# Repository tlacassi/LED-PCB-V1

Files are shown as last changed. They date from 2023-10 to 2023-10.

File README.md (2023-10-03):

# LED-PCB-V1

Une vidéo qui explique le minimum nécessaire pour faire tourner l'ESP sur un pcb : https://www.youtube.com/watch?v=tQ0dL_9M1wI&t=242s

Le projet WLED pour le soft et les intégrations : https://kno.wled.ge

Datasheet WS2815b : https://www.marutsu.co.jp/contents/shop/marutsu/datasheet/WS2815B.pdf

Datasheet ESP32 : https://www.espressif.com/sites/default/files/documentation/esp32-s3-wroom-1_wroom-1u_datasheet_en.pdf

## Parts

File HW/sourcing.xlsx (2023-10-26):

Reference | Qty | Value | Footprint | REF 1 | Prix 1 CHF | REF 2 | Prix 2 CHF | REF 3 | Prix 3 CHF
Régulateur | 1 | 5v to 3v3 | Package_TO_SOT_SMD:TO-252-3_TabPin2 | AZ1117CR-3.3TRG1 | 0.307
DCDC | 1 | 12v to 5v | Package_TO_SOT_SMD:TO-252-3_TabPin2 | TSR-1-2450 | 4.99
Condensateurs : C1, C2, C3, C4, C6, C7, C9, C10, C11, C15 | 10 | 100nF |  | MCASU105SB7104KFNA01 | 0.49
Condensateurs : C5, C8 | 2 | 1000uF/50V |  | A768MS108M1CLAE015 | 1.642 | EMZS250ARA102MJA0G | 1.57
Condensateurs : C12, C13, C14 | 3 | 1uF |  | GRM155C71C105KE11D | 0.27
Microcontrôleur | 1 | ESP32 |  | ESP32-S3-WROOM-1-N8 | 2.89
Fusible F1 | 1 | 7A |  | 5MF 7-R | 0.541 | 0235007.MXP | 0.406 | BK1/GMA-7-R | 0.541
Porte fusible | 1 | Porte fuse 5*20mm |  | 0031.8201.G | 0.767 | BK1/HTC-100M | 0.722
Connecteur USB C : J1 | 1 | USB_C_Receptacle |  | 216990-0002 | 0.837
Connecteurs de sortie : J5, J7 | 2 | 4 pins right angle |  | 39-30-3041 | 1.552
Connecteur d'alimentation | 1 | Jack-DC |  | PJ-057AH | 0.965 | 694106301002 | 0.921
Level shifter | 1 | 0-3.3V to 0-5V |  | SN74AHCT125DR | 0.335
Relais | 1 |  |  | AHQSH112LM1F00G | 0.837
Diode de roue libre | 1 |  |  | 1N4148W_R1_00001 | 0.121
Transistor commande relais | 1 |  |  | MMBT3904-7-F | 0.102
Bouton reset | 1 |  |  | TS14-1212-140-BK-160-SCR-D | 0.251
Nb PCB
10

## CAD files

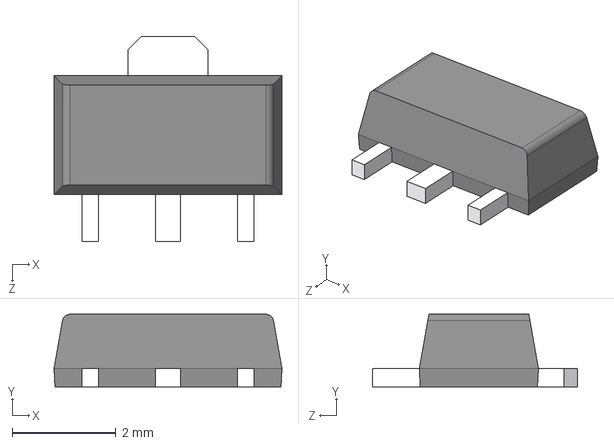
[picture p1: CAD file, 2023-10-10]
HW/wled_V1/AZ1117CR-3.3TRG1.stp
4.40 x 1.40 x 3.95 mm

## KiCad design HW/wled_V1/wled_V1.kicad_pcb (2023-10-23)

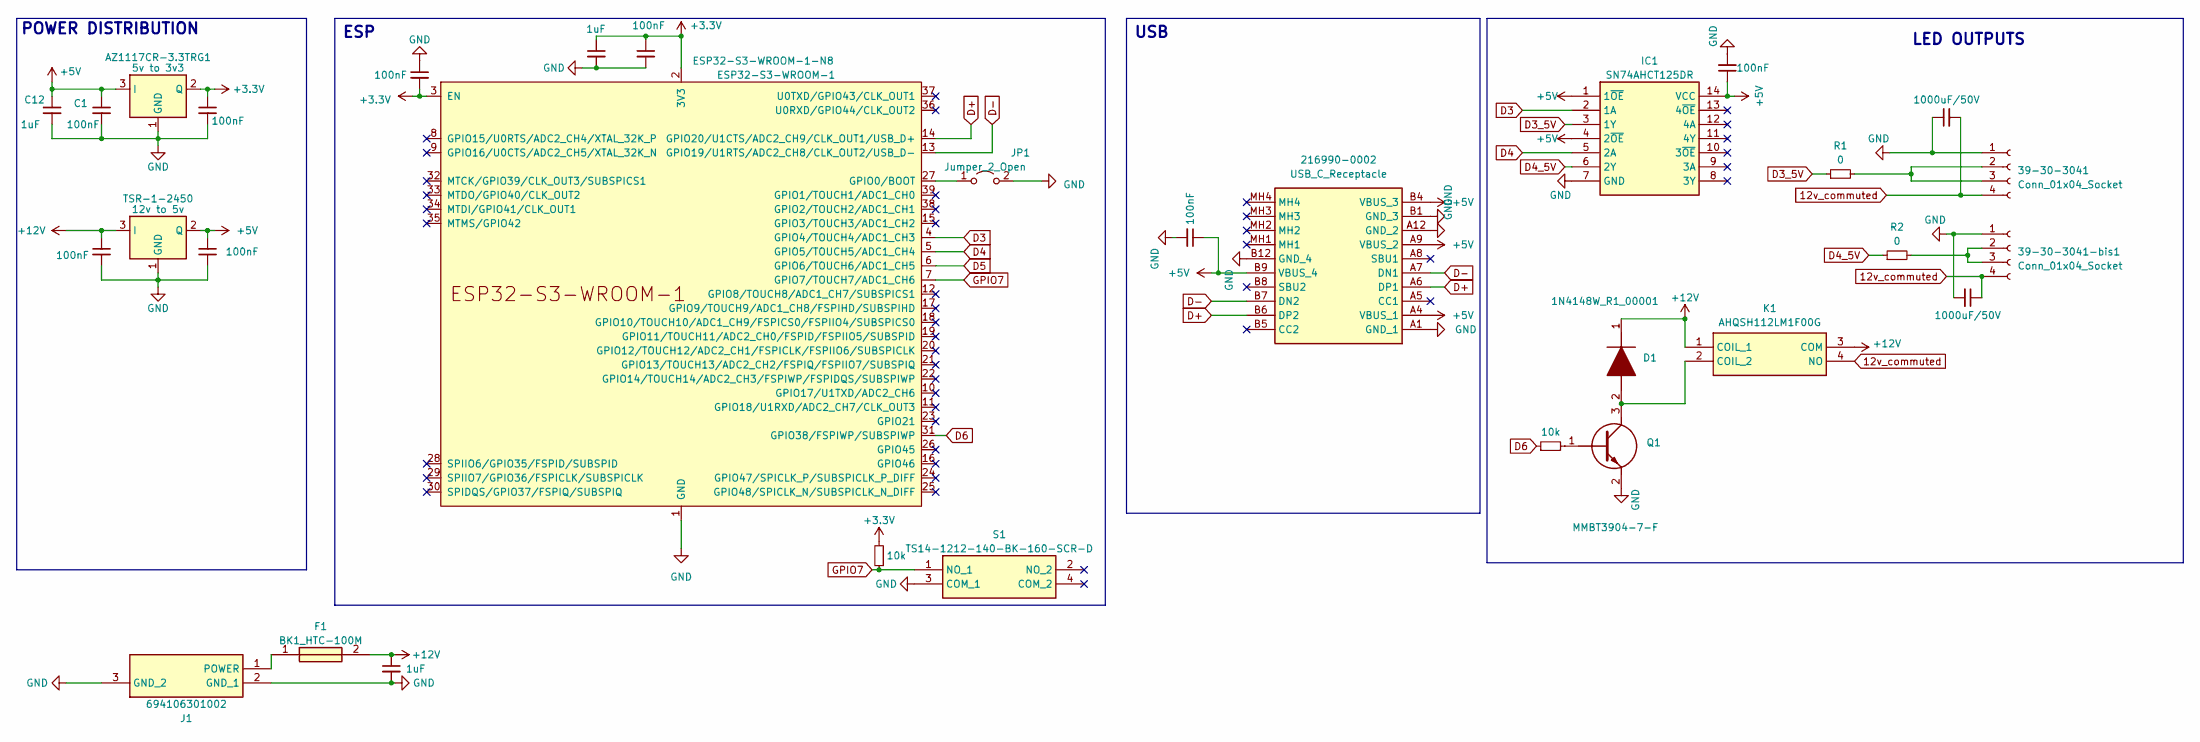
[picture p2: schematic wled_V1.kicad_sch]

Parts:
39-30-3041, 39-30-3041-bis1: Conn_01x04_Socket; 39303041
216990-0002: USB_C_Receptacle; 2169900002; Mouser Part Number 538-216990-0002
AZ1117CR-3.3TRG1: 5v to 3v3; AZ1117CR33TRG1
C1, C2, C3, C4, C6, C9, C11, C0402C103K1RACAUTO1: 100nF; CAPC1005X55N
C5, C8: 1000uF/50V; CAPAE1030X1050N
C12, C13, C14: 1uF; CAPC1005X55N
D1: 1N4148W_R1_00001; SOD3816X135N; Mouser Part Number 241-1N4148W_R1_00001
ESP32-S3-WROOM-1-N8: ESP32-S3-WROOM-1; ESP32S3WROOM1N8R8
F1: BK1_HTC-100M; BK1HTC100M; Mouser Part Number 504-BK1-HTC-100M
IC1: SN74AHCT125DR; SOIC127P600X175-14N; Mouser Part Number 595-SN74AHCT125DR
J1: 694106301002; 694106301002_1; Mouser Part Number 710-694106301002
JP1: Jumper_2_Open; SolderJumper-2_P1.3mm_Bridged2Bar_Pad1.0x1.5mm
K1: AHQSH112LM1F00G; Mouser Part Number 523-AHQSH112LM1F00G
Q1: MMBT3904-7-F; SOT96P240X110-3N; Mouser Part Number 621-MMBT3904-F
R1, R2: 0; R_0603_1608Metric_Pad0.98x0.95mm_HandSolder
RN73H1JTTD1002F1, RN73H1JTTD1002F50: 10k; R_0603_1608Metric_Pad0.98x0.95mm_HandSolder
S1: TS14-1212-140-BK-160-SCR-D; TS0266160BK260LCRD; Manufacturer_Part_Number TS14-1212-140-BK-160-SCR-D
TSR-1-2450: 12v to 5v; TSR12450

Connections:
12v_commuted: 39-30-3041.4, 39-30-3041-bis1.4, C5.1, C8.2, K1.4 (NO)
+3.3V: AZ1117CR-3.3TRG1.2 (Q), C2.1, C6.2, C14.1, C0402C103K1RACAUTO1.1, ESP32-S3-WROOM-1-N8.2 (3V3), ESP32-S3-WROOM-1-N8.3 (EN), RN73H1JTTD1002F1.2; also elsewhere on the board
+5V: 216990-0002.A4 (VBUS_1), 216990-0002.A9 (VBUS_2), 216990-0002.B4 (VBUS_3), 216990-0002.B9 (VBUS_4), AZ1117CR-3.3TRG1.3 (I), C1.1, C4.1, C9.1, C11.1, C12.1, IC1.1 (1~OE), IC1.4 (2~OE), IC1.14 (VCC), TSR-1-2450.2 (Q)
+12V: C3.1, C13.1, D1.1 (K), F1.2, K1.1 (COIL_1), K1.3 (COM), TSR-1-2450.3 (I)
D3: ESP32-S3-WROOM-1-N8.4 (GPIO4/TOUCH4/ADC1_CH3), IC1.2 (1A)
D3_5V: IC1.3 (1Y), R1.1
D4: ESP32-S3-WROOM-1-N8.5 (GPIO5/TOUCH5/ADC1_CH4), IC1.5 (2A)
D4_5V: IC1.6 (2Y), R2.1
D5: ESP32-S3-WROOM-1-N8.6 (GPIO6/TOUCH6/ADC1_CH5)
D6: ESP32-S3-WROOM-1-N8.31 (GPIO38/FSPIWP/SUBSPIWP), RN73H1JTTD1002F50.1
D+: 216990-0002.A6 (DP1), 216990-0002.B6 (DP2), ESP32-S3-WROOM-1-N8.14 (GPIO20/U1CTS/ADC2_CH9/CLK_OUT1/USB_D+)
D-: 216990-0002.A7 (DN1), 216990-0002.B7 (DN2), ESP32-S3-WROOM-1-N8.13 (GPIO19/U1RTS/ADC2_CH8/CLK_OUT2/USB_D-)
GND: 39-30-3041.1, 39-30-3041-bis1.1, 216990-0002.A1 (GND_1), 216990-0002.A12 (GND_2), 216990-0002.B1 (GND_3), 216990-0002.B12 (GND_4), AZ1117CR-3.3TRG1.1 (GND), C1.2, C3.2, C4.2, C5.2, C8.1, C9.2, C11.2, C12.2, C13.2, C14.2, C0402C103K1RACAUTO1.2, ESP32-S3-WROOM-1-N8.1 (GND), ESP32-S3-WROOM-1-N8.40 (GND), ESP32-S3-WROOM-1-N8.41 (GND), IC1.7 (GND), J1.2 (GND_1), J1.3 (GND_2), JP1.2 (B), Q1.2 (E), S1.3 (COM_1), TSR-1-2450.1 (GND); also elsewhere on the board
GPIO7: ESP32-S3-WROOM-1-N8.7 (GPIO7/TOUCH7/ADC1_CH6), RN73H1JTTD1002F1.1, S1.1 (NO_1)
unnamed: 39-30-3041.2, 39-30-3041.3, R1.2
unnamed: 39-30-3041-bis1.2, 39-30-3041-bis1.3, R2.2
unnamed: D1.2 (A), K1.2 (COIL_2), Q1.3 (C)
unnamed: ESP32-S3-WROOM-1-N8.27 (GPIO0/BOOT), JP1.1 (A)
unnamed: F1.1, J1.1 (POWER)
unnamed: Q1.1 (B), RN73H1JTTD1002F50.2

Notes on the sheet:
USB
LED OUTPUTS
ESP
POWER DISTRIBUTION

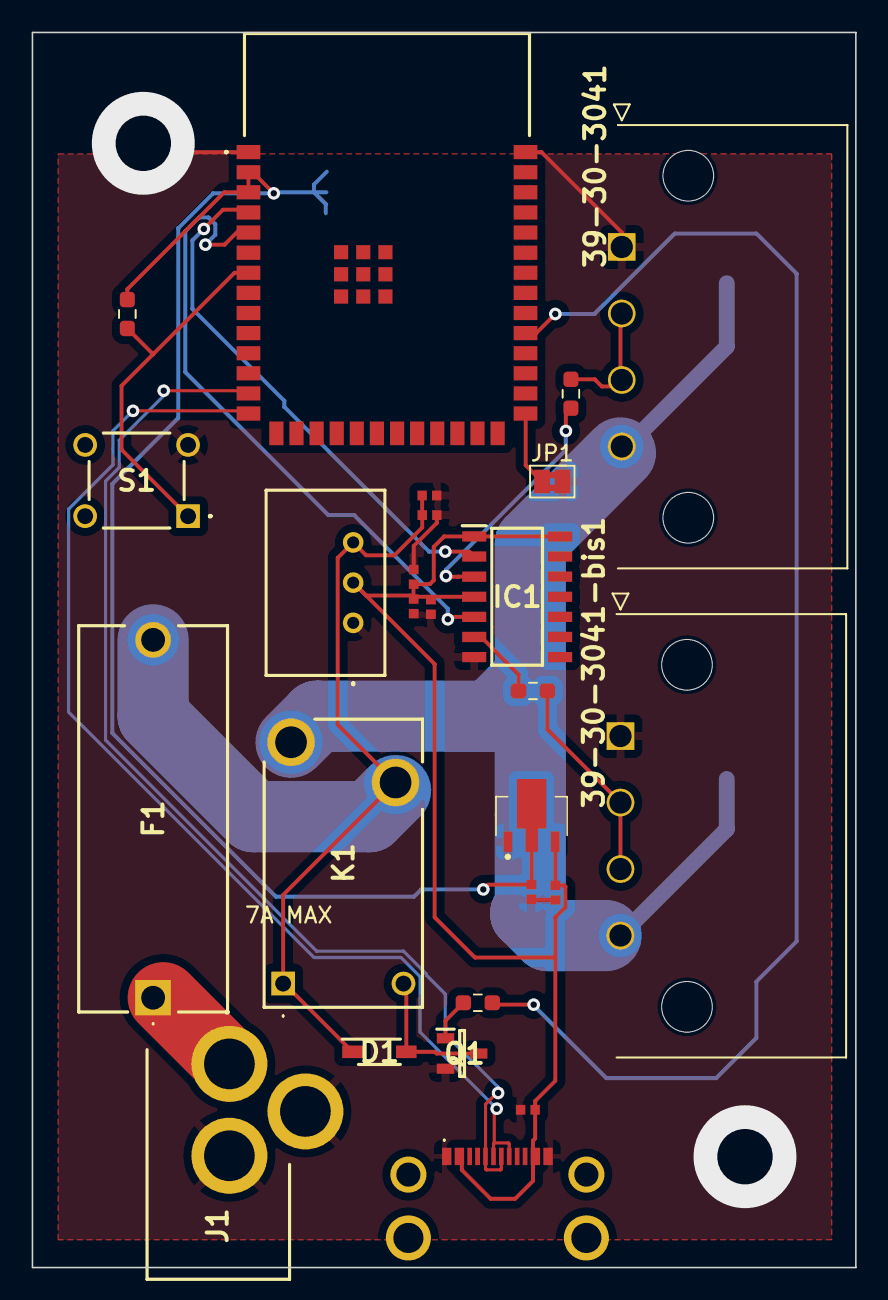
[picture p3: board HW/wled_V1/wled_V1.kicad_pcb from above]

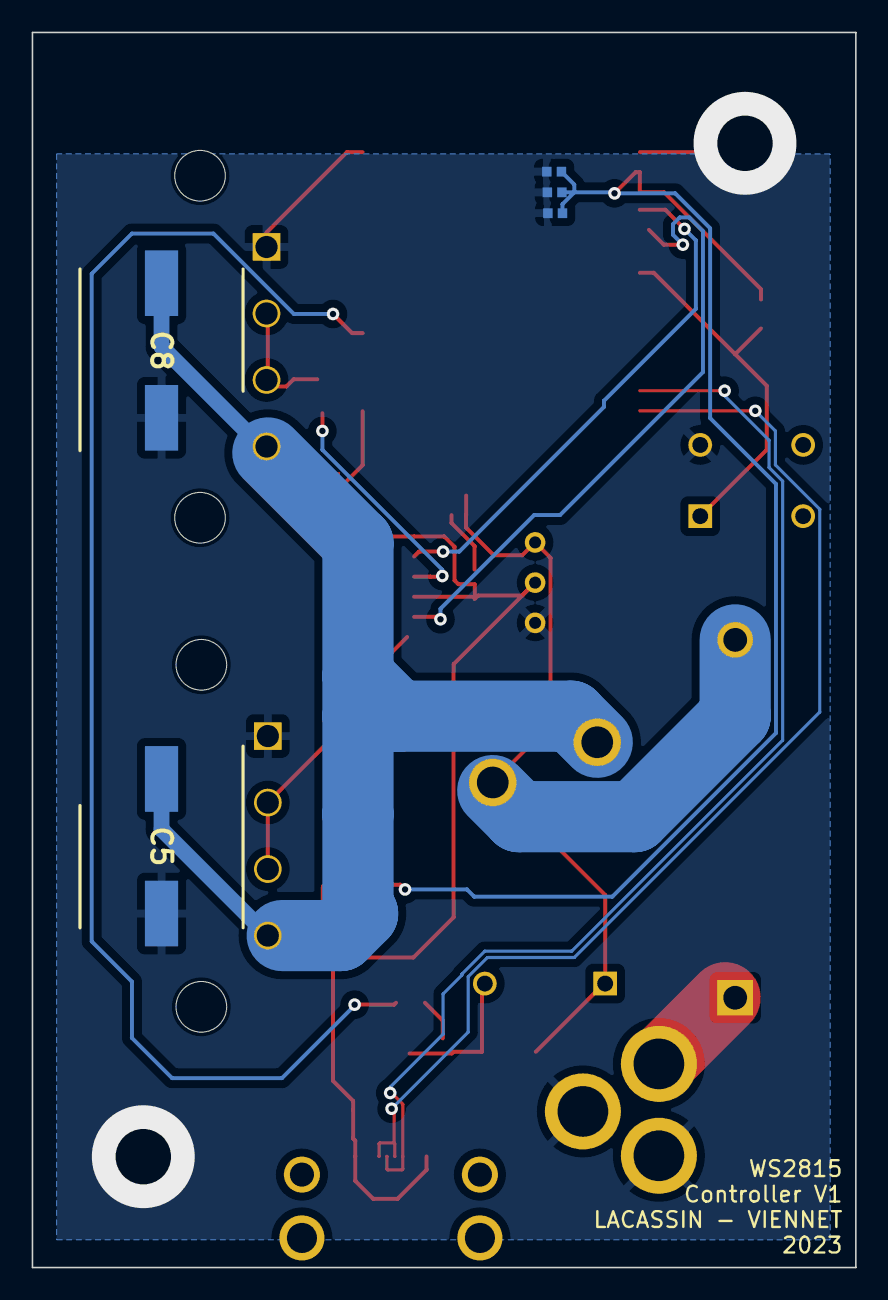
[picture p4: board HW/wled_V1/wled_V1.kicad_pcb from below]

Board: 2 copper layers, 52.0 x 78.0 mm, 31 parts (5 on the bottom side), 19 nets.

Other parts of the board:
C10, C15: 100nF; CAPC1005X55N

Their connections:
+3.3V: C10.1, C15.1; also elsewhere on the board
GND: C10.2, C15.2; also elsewhere on the board

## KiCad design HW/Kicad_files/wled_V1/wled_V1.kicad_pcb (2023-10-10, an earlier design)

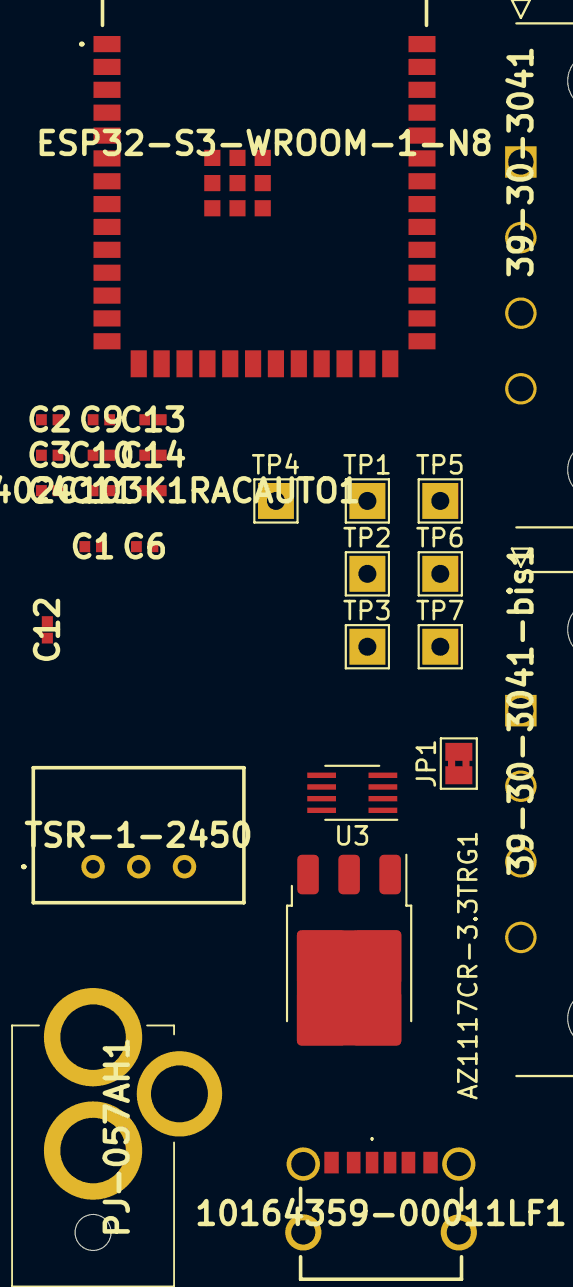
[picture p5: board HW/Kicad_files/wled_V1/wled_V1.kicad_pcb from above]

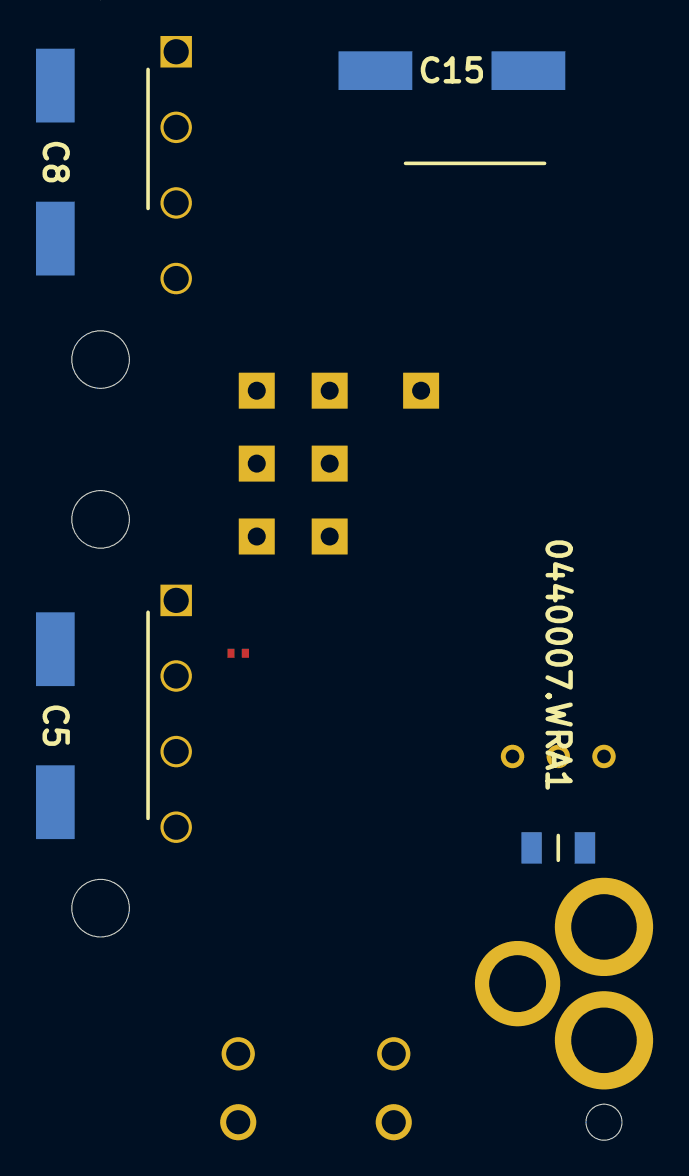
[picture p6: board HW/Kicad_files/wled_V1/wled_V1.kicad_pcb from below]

Board: 2 copper layers, 32 parts (4 on the bottom side), 12 nets, no tracks yet.

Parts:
39-30-3041, 39-30-3041-bis1: Conn_01x04_Socket; 39303041
0440007.WRA1: Fuse; FUSC3216X85N
10164359-00011LF1: USB_C_Receptacle; 1016435900011LF
AZ1117CR-3.3TRG1: 5v to 3v3; TO-252-3_TabPin2
C1, C2, C3, C4, C6, C9, C10, C11, C0402C103K1RACAUTO1: 100nF; CAPC1005X55N
C5, C8: 1000uF/50V; CAPAE1030X1030N
C12, C13, C14: 1uF; CAPC1005X55N
C15: 100nF; CAPAE1030X1030N
ESP32-S3-WROOM-1-N8: ESP32-S3-WROOM-1; ESP32S3WROOM1N8R8
JP1: Jumper_2_Open; SolderJumper-2_P1.3mm_Bridged2Bar_Pad1.0x1.5mm
PJ-057AH1: Jack-DC; PJ057AH
TP1, TP2, TP3, TP4, TP5, TP6, TP7: TestPoint; TestPoint_THTPad_2.0x2.0mm_Drill1.0mm
TSR-1-2450: 12v to 5v; TSR12450
U3: TXS0102DCT; SSOP-8_2.95x2.8mm_P0.65mm

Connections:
+3.3V: AZ1117CR-3.3TRG1.2 (Q), C2.1, C6.2, C10.1, C14.1, C15.1, C0402C103K1RACAUTO1.1, ESP32-S3-WROOM-1-N8.2 (3V3), ESP32-S3-WROOM-1-N8.3 (EN), TP2.1, U3.3 (VCCA), U3.6 (OE)
+5V: 10164359-00011LF1.A9 (VBUS), 10164359-00011LF1.B9 (VBUS), AZ1117CR-3.3TRG1.3 (I), C1.1, C4.1, C9.1, C11.1, C12.1, TSR-1-2450.2 (Q), U3.7 (VCCB)
+12V: 39-30-3041.4, 39-30-3041-bis1.4, 0440007.WRA1.2, C3.1, C5.1, C8.2, C13.1, TP1.1, TSR-1-2450.3 (I)
D3: ESP32-S3-WROOM-1-N8.4 (GPIO4/TOUCH4/ADC1_CH3), TP3.1, U3.5 (A1)
D4: ESP32-S3-WROOM-1-N8.5 (GPIO5/TOUCH5/ADC1_CH4), TP4.1, U3.4 (A2)
D5: ESP32-S3-WROOM-1-N8.6 (GPIO6/TOUCH6/ADC1_CH5), TP5.1
D6: ESP32-S3-WROOM-1-N8.7 (GPIO7/TOUCH7/ADC1_CH6), TP6.1
GND: 39-30-3041.1, 39-30-3041-bis1.1, 10164359-00011LF1.A12 (GND), 10164359-00011LF1.B12 (GND), AZ1117CR-3.3TRG1.1 (GND), C1.2, C2.2, C3.2, C4.2, C5.2, C6.1, C8.1, C9.2, C10.2, C11.2, C12.2, C13.2, C14.2, C15.2, C0402C103K1RACAUTO1.2, ESP32-S3-WROOM-1-N8.1 (GND), ESP32-S3-WROOM-1-N8.40 (GND), ESP32-S3-WROOM-1-N8.41 (GND), JP1.2 (B), PJ-057AH1.2, TP7.1, TSR-1-2450.1 (GND), U3.2 (GND)
unnamed: 39-30-3041.2, 39-30-3041.3, U3.8 (B1)
unnamed: 39-30-3041-bis1.2, 39-30-3041-bis1.3, U3.1 (B2)
unnamed: 0440007.WRA1.1, PJ-057AH1.1
unnamed: ESP32-S3-WROOM-1-N8.27 (GPIO0/BOOT), JP1.1 (A)

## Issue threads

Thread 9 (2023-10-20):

Déplacer composants pour les rendre affleurant avec le bord du boitier

JulienSoftcar, 2023-10-20:
Le boitier étant plus large que le pcb, il va falloir déplacer les composants vers l'extérieur pour pouvoir les connecter correctement.

Closed 2023-12-06.

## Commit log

2023-10-02 ajout schemas kicad
    [wled_V1.kicad_pcb, wled_V1.kicad_sch]
2023-10-03 5v removed
    [wled_V1.kicad_sch]
2023-10-03 Power supply update
    [wled_V1.kicad_sch]
2023-10-05 Ajout filtrage
    [wled_V1.kicad_sch]
2023-10-06 Debut sourcing
    [sourcing.csv, wled_V1.kicad_sch]
2023-10-09 refs updated + lib
    [sourcing.csv, wled_V1.kicad_pcb, wled_V1.kicad_sch]
2023-10-10 Maj préparation pour sourcing
    [sourcing.csv]
2023-10-10 routing update
    [wled_V1.kicad_pcb, wled_V1.kicad_sch]
2023-10-11 supp csv
    [sourcing.csv, sourcing.xlsx]
2023-10-14 routing suite
    [wled_V1.kicad_pcb]
2023-10-17 nouveau level shifter + emplacement resistors. A router
    [wled_V1.kicad_sch]
2023-10-18 ref alternative porte fuse, Théo le zozo va procéder à des mesures de grande importance
    [sourcing.xlsx]
2023-10-19 Ajout ref connecteur alim
    [sourcing.xlsx]
2023-10-19 new parts and routing
    [wled_V1.kicad_pcb, wled_V1.kicad_sch]
2023-10-19 mounting points added
    [wled_V1.kicad_pcb]
2023-10-20 added relay
    [wled_V1.kicad_sch]
2023-10-26 Sourcing maj
    [sourcing.xlsx, wled_V1.kicad_sch]
